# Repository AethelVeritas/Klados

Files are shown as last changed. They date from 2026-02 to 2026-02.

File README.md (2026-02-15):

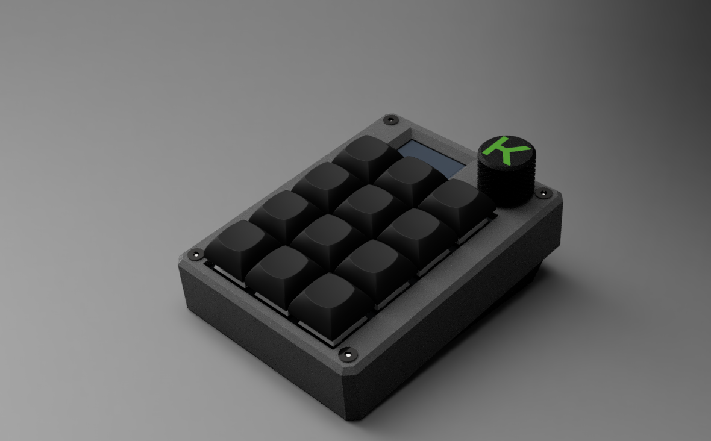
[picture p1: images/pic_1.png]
Top view


# Klados
*'klados' - Greek for branch, offshoot*  
Like a branch from a tree, this macropad is designed to be an extension of your keyboard.  
This is version two of my macropad, made for [Hackpad](https://hackpad.hackclub.com) and now redesigned for [Reboot](https://reboot.hackclub.com).  
See the initial version [here](https://github.com/AethelVeritas/hackpad/tree/main/hackpads/One%20Pad%20To%20Rule%20Them%20All).

<!-- Hack Club Badge -->
<a href="https://hackpad.hackclub.com/">
  
</a>

---

# Gallery
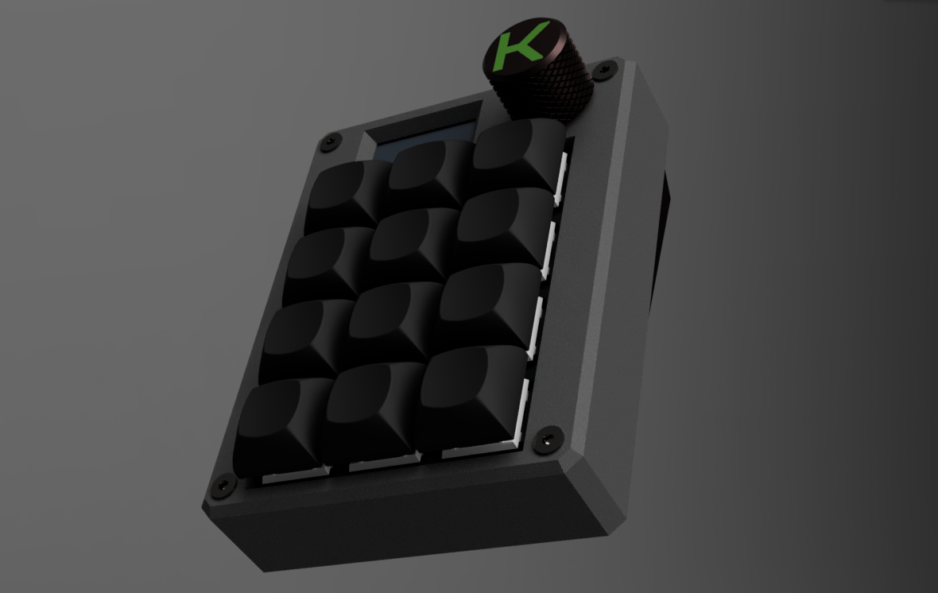
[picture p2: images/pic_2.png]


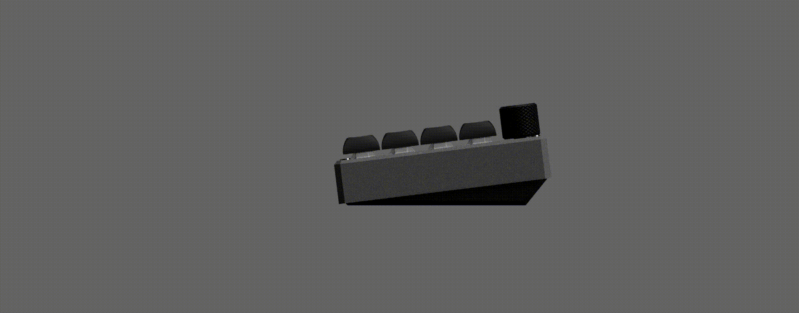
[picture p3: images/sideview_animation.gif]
Side view animation

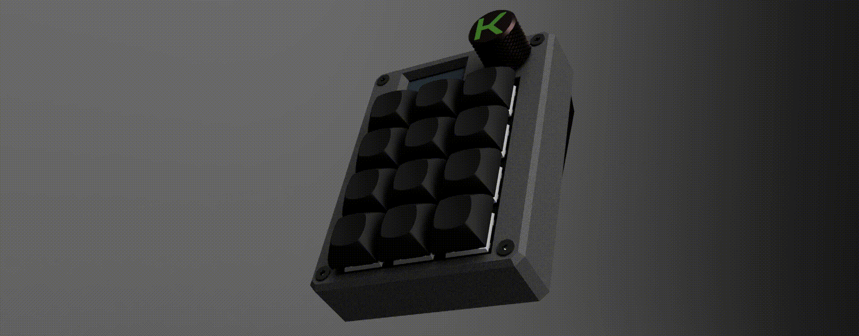
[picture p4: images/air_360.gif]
360° view

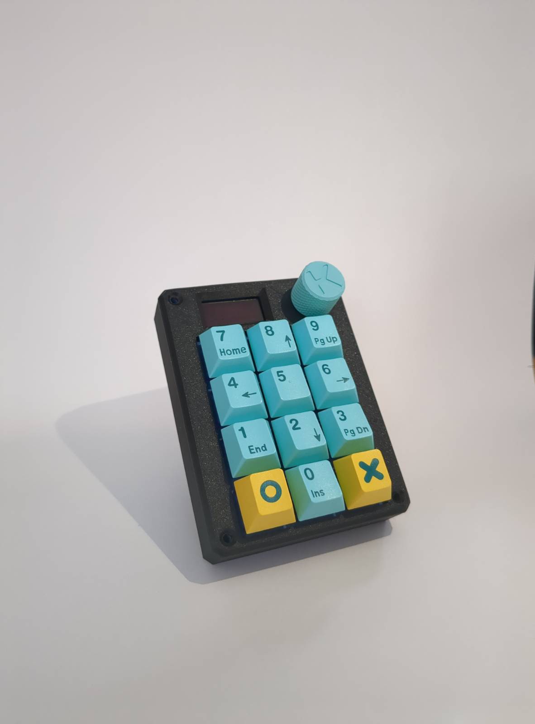
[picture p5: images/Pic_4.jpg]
Real pic

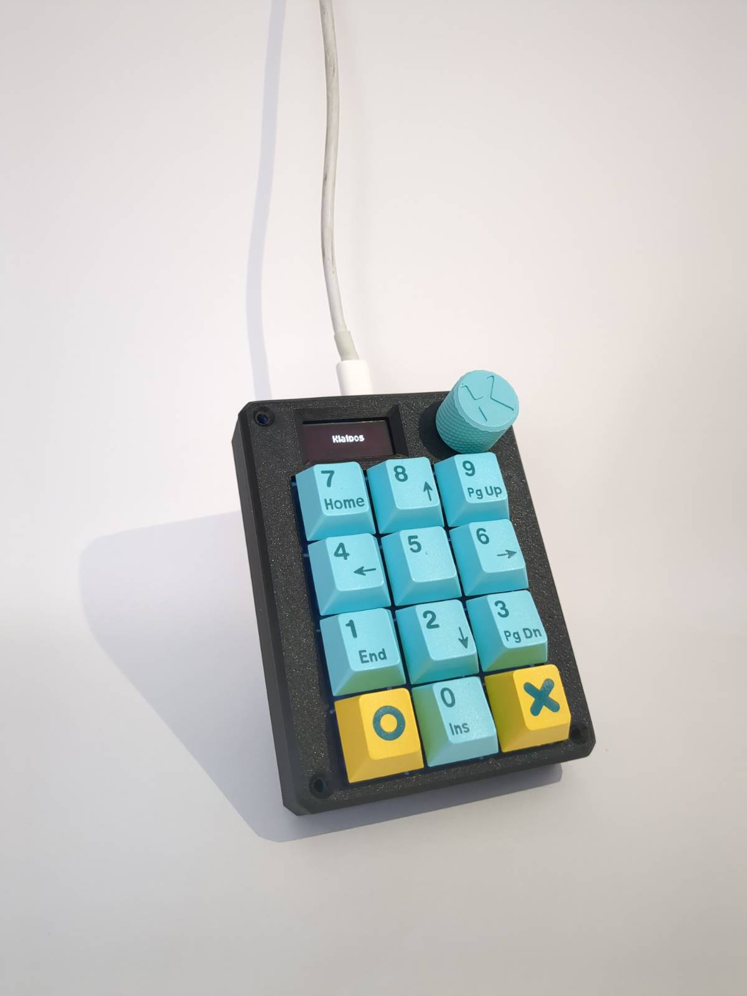
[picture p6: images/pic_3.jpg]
Real pic OLED

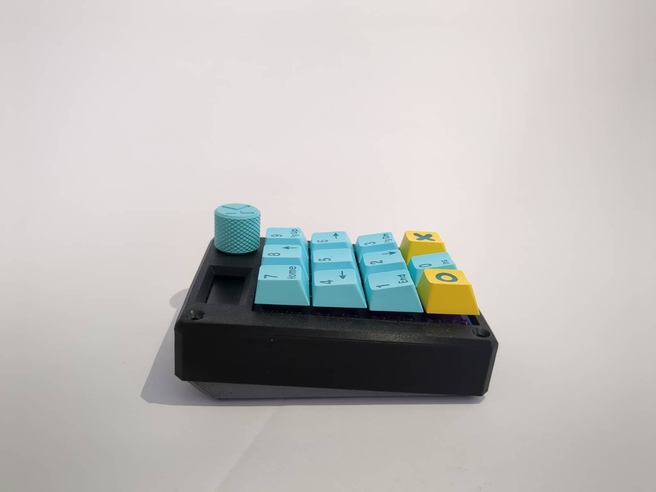
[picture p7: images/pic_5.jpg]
Real pic side view


# BOM
- 1 x Seeed Xiao RP2040 MCU
- 12 x Cherry MX switches
- 12 x DSA/MX compatible keycaps
- 1 x EC11E/EC11 rotary encoder
- 1 x 128*32 SSD1306 OLED screen
- 1 x PCB
- 4 x M3 * 16-18mm flathead screws
- 4 x M3 heat inserts
- 1 x Printed switch plate 
- 1 x Printed case 
- 1 x Printed bottom plate 
- 1 x Encoder knob 

# License

Klados is licensed under CERN-OHL-P-2.0.

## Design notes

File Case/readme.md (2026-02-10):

The Onshape document can be found [here](https://cad.onshape.com/documents/9fcccc96fdf635957faaf081/w/908abfb6b5d8bd4c0698acf9/e/21b1e8287d7ad5fad269d9f2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).
The encoder knob can be printed vertically, with supports. If you don't have a printer compatible with multicolor, you can remove the "K" object/part in your slicer of choice before printing. A single color friendly encoder dual-color encoder knob might be added in the future.

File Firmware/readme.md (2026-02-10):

# klados

klados

A 12 key macropad, with a display and encoder. 

* Keyboard Maintainer: [AethelVeritas](https://github.com/AethelVeritas)
* Hardware Supported: *The PCBs, controllers supported*
* Hardware Availability: [Aliexpress](aliexpress.com) 

Make example for this keyboard (after setting up your build environment):

    make klados:default

Flashing example for this keyboard:

    make klados:default:flash

See the [build environment setup](https://docs.qmk.fm/#/getting_started_build_tools) and the [make instructions](https://docs.qmk.fm/#/getting_started_make_guide) for more information. Brand new to QMK? Start with our [Complete Newbs Guide](https://docs.qmk.fm/#/newbs).

## Bootloader

Enter the bootloader in 3 ways:

* **Bootmagic reset**: Hold down the key at (0,0) in the matrix (usually the top left key or Escape) and plug in the keyboard
* **Physical reset button**: Briefly press the button on the back of the PCB - some may have pads you must short instead
* **Keycode in layout**: Press the key mapped to `QK_BOOT` if it is available

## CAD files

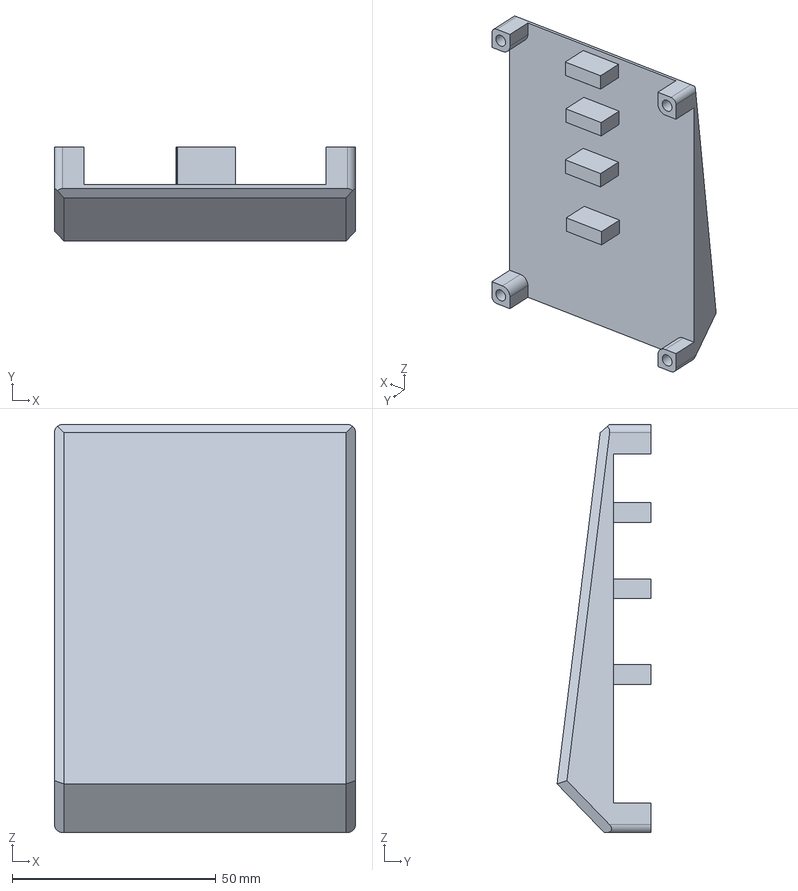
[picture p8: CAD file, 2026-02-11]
Case/Bottom_Plate.step
73.8 x 23.0 x 100.0 mm

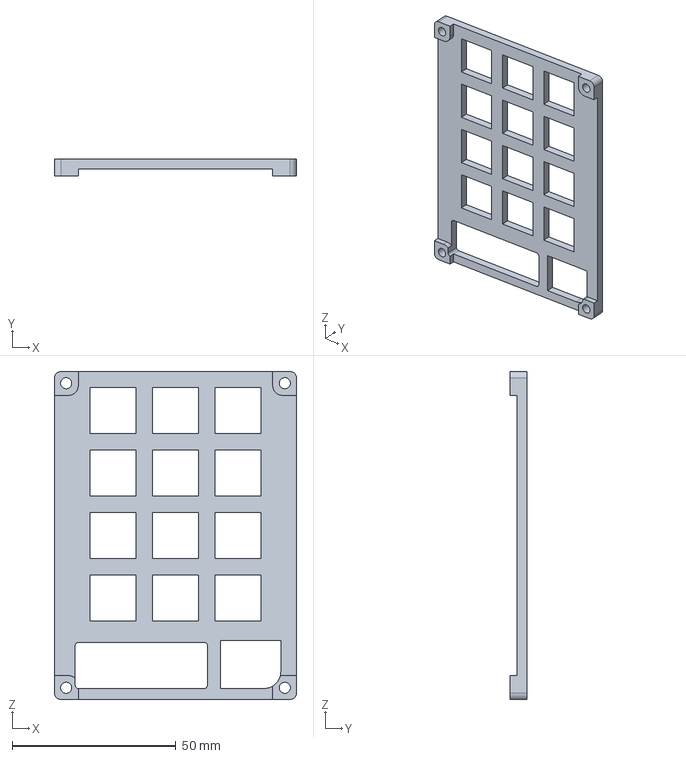
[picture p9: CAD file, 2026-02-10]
Case/Switch_Plate.step
73.8 x 5.09 x 100.0 mm

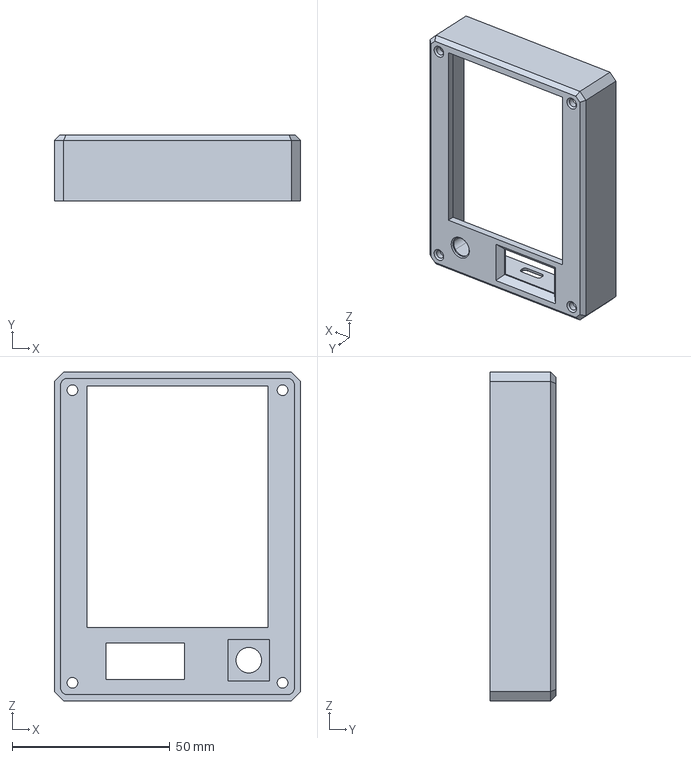
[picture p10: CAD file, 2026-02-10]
Case/Case.step
78.2 x 21.0 x 104.4 mm

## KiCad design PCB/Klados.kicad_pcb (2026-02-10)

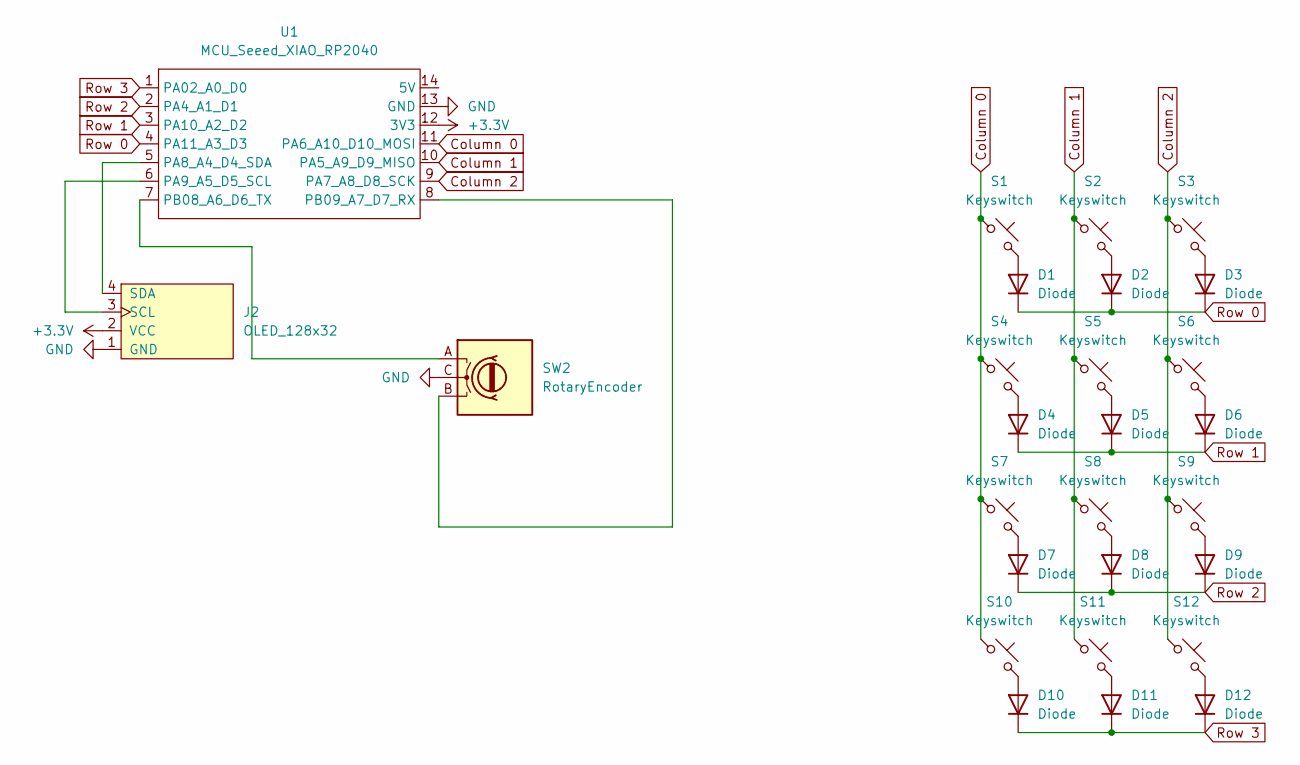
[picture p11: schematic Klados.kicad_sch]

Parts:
D1, D2, D3, D4, D5, D6, D7, D8, D9, D10, D11, D12: Diode; Diode_DO-35
J2: OLED_128x32
S1, S2, S3, S4, S5, S6, S7, S8, S9, S10, S11, S12: Keyswitch; MX_PCB_1.00u
SW2: RotaryEncoder; RotaryEncoder_Alps_EC11E_Vertical_H20mm
U1: MCU_Seeed_XIAO_RP2040; Seeed_XIAO_RP2040

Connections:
+3.3V: J2.2 (VCC), U1.12 (3V3)
Column 0: S1.1, S4.1, S7.1, S10.1, U1.11 (PA6_A10_D10_MOSI)
Column 1: S2.1, S5.1, S8.1, S11.1, U1.10 (PA5_A9_D9_MISO)
Column 2: S3.1, S6.1, S9.1, S12.1, U1.9 (PA7_A8_D8_SCK)
GND: J2.1 (GND), SW2.C, U1.13 (GND)
unnamed: D1.2 (A), S1.2
unnamed: D2.2 (A), S2.2
unnamed: D3.2 (A), S3.2
unnamed: D4.2 (A), S4.2
unnamed: D5.2 (A), S5.2
unnamed: D6.2 (A), S6.2
unnamed: D7.2 (A), S7.2
unnamed: D8.2 (A), S8.2
unnamed: D9.2 (A), S9.2
unnamed: D10.2 (A), S10.2
unnamed: D11.2 (A), S11.2
unnamed: D12.2 (A), S12.2
unnamed: J2.3 (SCL), U1.6 (PA9_A5_D5_SCL)
unnamed: J2.4 (SDA), U1.5 (PA8_A4_D4_SDA)
unnamed: SW2.A, U1.7 (PB08_A6_D6_TX)
unnamed: SW2.B, U1.8 (PB09_A7_D7_RX)
Row 0: D1.1 (K), D2.1 (K), D3.1 (K), U1.4 (PA11_A3_D3)
Row 1: D4.1 (K), D5.1 (K), D6.1 (K), U1.3 (PA10_A2_D2)
Row 2: D7.1 (K), D8.1 (K), D9.1 (K), U1.2 (PA4_A1_D1)
Row 3: D10.1 (K), D11.1 (K), D12.1 (K), U1.1 (PA02_A0_D0)

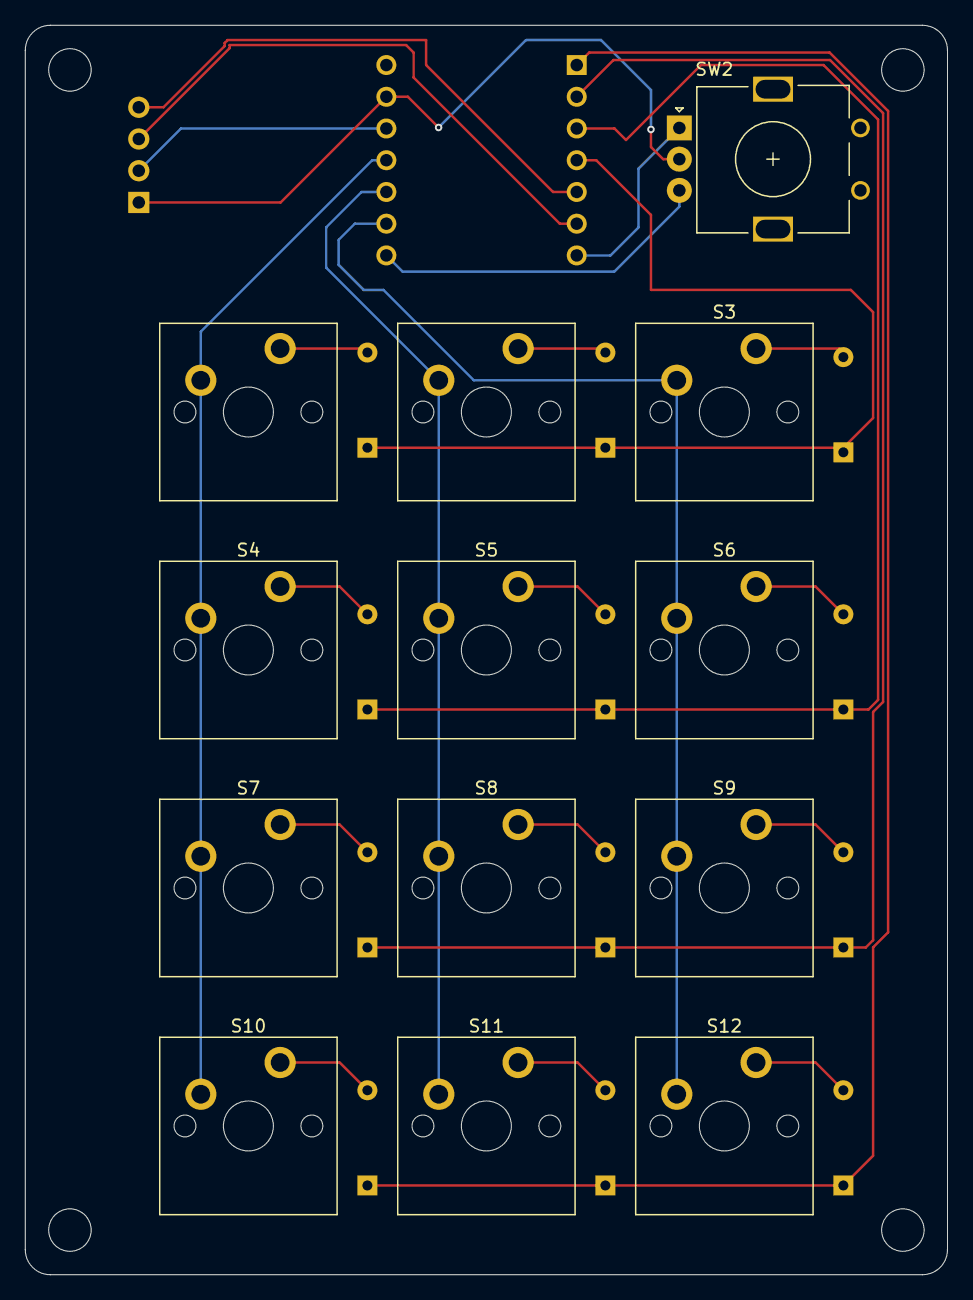
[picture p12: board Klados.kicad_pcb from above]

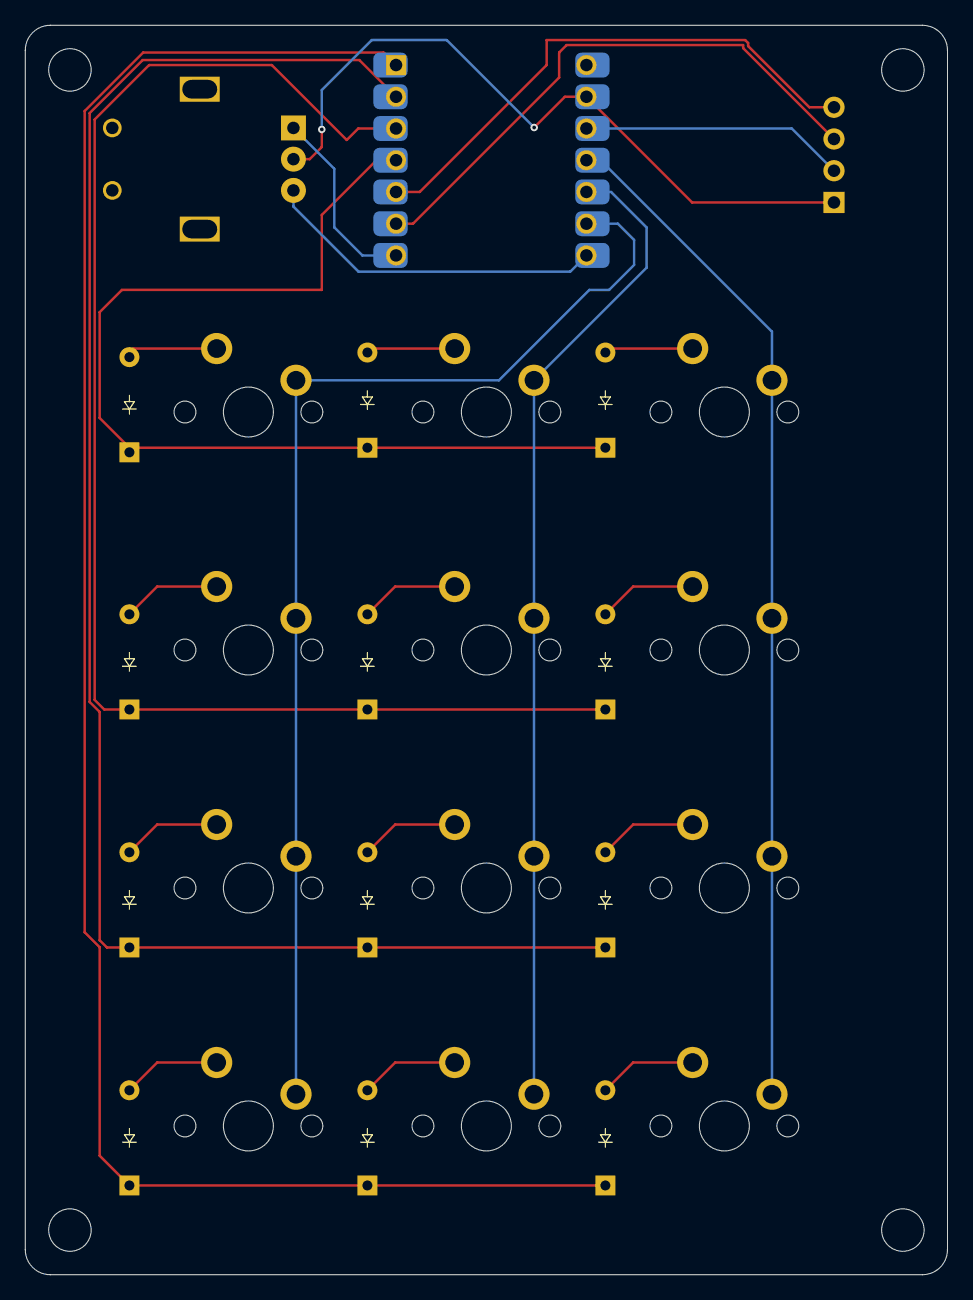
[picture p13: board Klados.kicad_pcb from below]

Board: 2 copper layers, 73.8 x 100.0 mm, 27 parts (13 on the bottom side), 25 nets.

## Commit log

2026-02-10 added case files, cleaned up a pcb file naming error
    [Bottom_Plate.step, Case.step, Switch_Plate.step]
2026-02-10 Transfered PCB files from old hackpad repo
    [Klados.kicad_pcb, Klados.kicad_sch]
2026-02-10 tidied up BOM and README.md
2026-02-10 added a readme to the Case folder and onshape link
2026-02-11 Added actual printed macropad images
2026-02-11 fixed readme real images, updated heat insert slots of bottom plate to 3.9 from 4.2 mm
    [Bottom_Plate.step]
